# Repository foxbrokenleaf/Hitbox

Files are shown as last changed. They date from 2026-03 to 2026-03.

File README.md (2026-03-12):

# HitBox

## 成品
微信图片_20260312213438_205_17

## 成本统计（因人而异）
### 原价（参考价）
+ 覆铜板15x20cm - 4.91￥
+ 猎隼mini矮轴*6 - 21￥
+ 猎隼mini矮轴*8 - 28￥
+ STM32F103C8T6 - 14.97￥
+ USB-B接口*5 - 3.35￥
+ 1x20p排母*10 - 2.62￥
### 使用优惠卷（我）
+ 覆铜板15x20cm - 2.22￥
+ 猎隼mini矮轴*6 - 15.8￥
+ 猎隼mini矮轴*8 - 16.8￥
+ STM32F103C8T6 - 2.47￥
+ USB-B接口*5 - 0.95￥
+ 1x20p排母*10 - 2.62￥
## PCB成品预览
正面预览图

## 制板
### 热转印法
#### 工具材料
+ 热转印机/熨斗
+ 热转印纸
+ 激光打印机
+ 覆铜板
+ 砂纸/钢丝球
+ 蚀刻剂
#### 热转印
使用激光打印机将镜像的PCB打印到转印纸（反光面）上，然后使用热转印机或者熨斗按压转印，然后缓慢揭开热转印纸

#### 蚀刻
配置蚀刻液，将转印好的PCB放入蚀刻液中，确保溶液没过PCB板


### 感光法（未购买相关材料）

## 3D打印键帽
### 正面

### 背面

## 后续更新
+ 将最小系统板改为芯片
+ 将USB-B改为Type-C

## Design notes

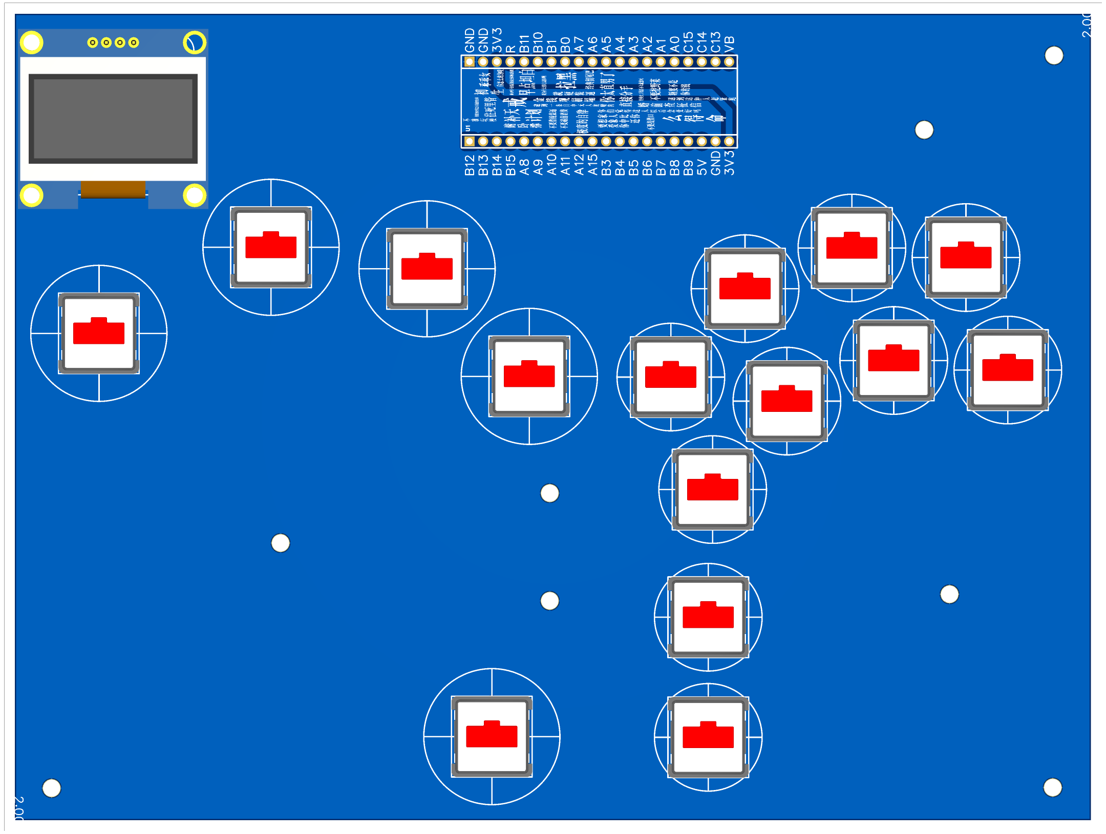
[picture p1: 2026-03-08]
EleCircurt/正面预览图.png

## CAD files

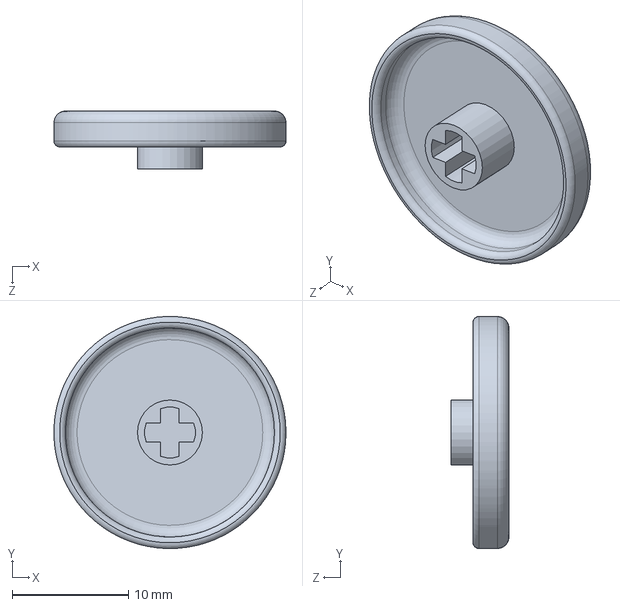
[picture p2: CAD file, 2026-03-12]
3DMoudle/HitboxKey-20mm.SLDPRT
20.0 x 20.0 x 5.00 mm

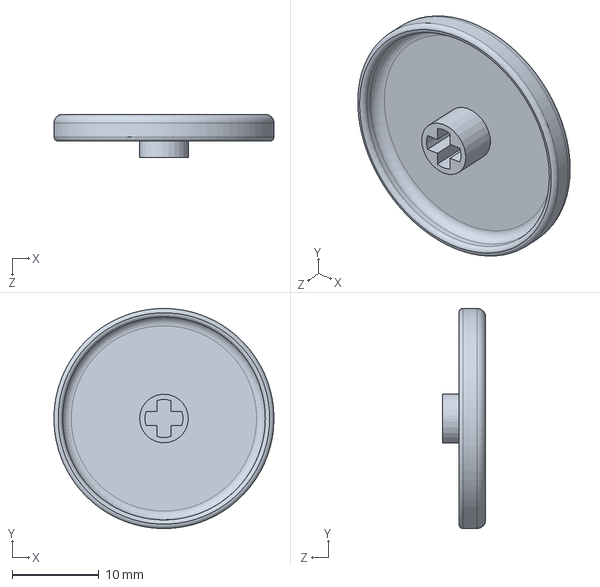
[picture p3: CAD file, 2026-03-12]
3DMoudle/HitboxKey-25_3mm.SLDPRT
25.3 x 25.3 x 5.00 mm

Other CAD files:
3DMoudle/HitboxKey-20mm.3MF
3DMoudle/HitboxKey-25_3mm.3MF

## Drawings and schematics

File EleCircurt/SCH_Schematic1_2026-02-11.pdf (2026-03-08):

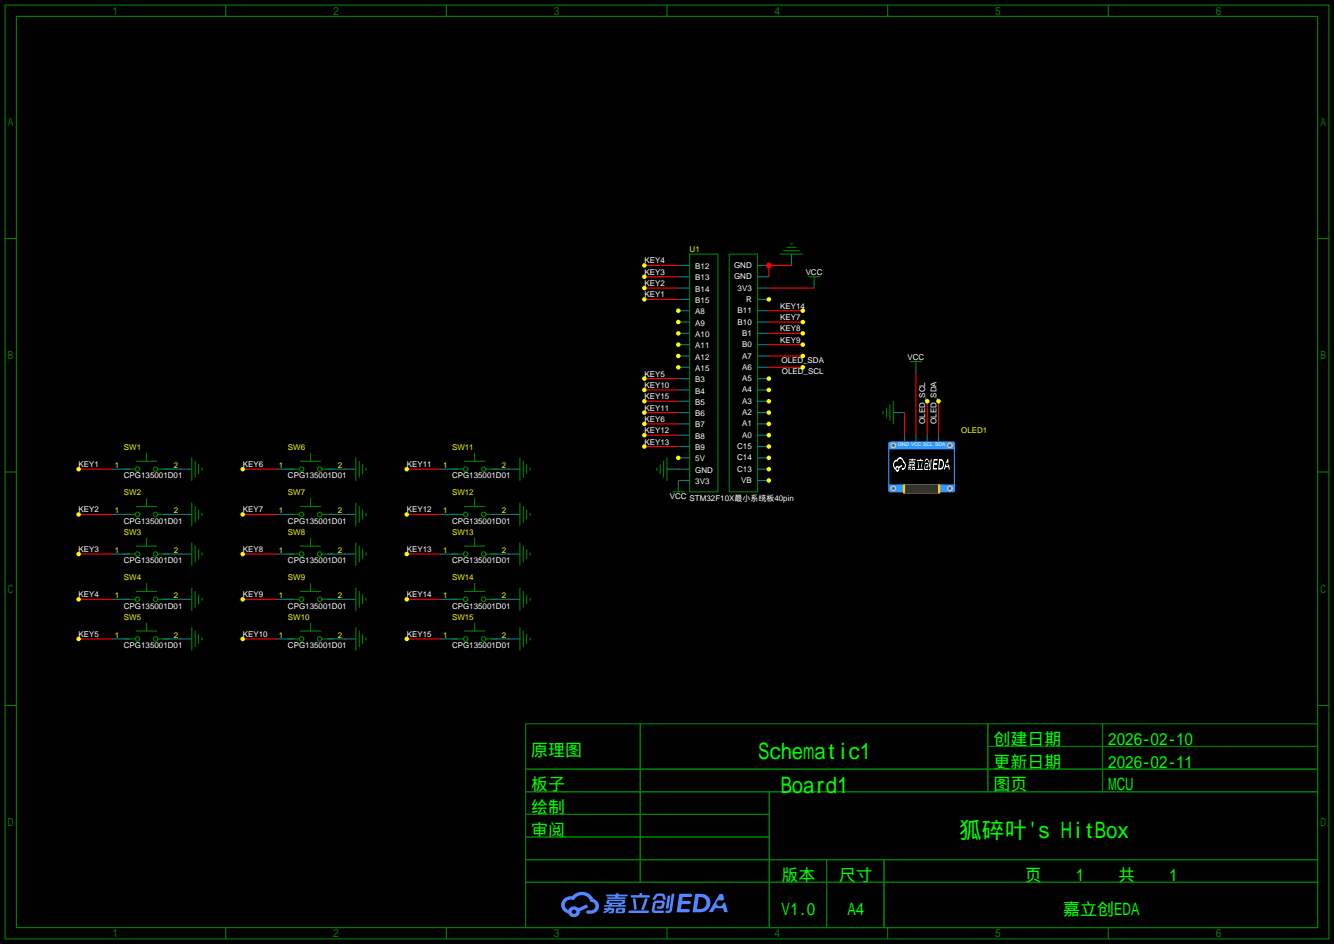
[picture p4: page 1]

GND VCC SCL SDA

原理图 | Schematic1 | 创建日期 | 2026-02-10

更新日期 | 2026-02-11

板子 | Board1 | 图页 | MCU
绘制 | | 狐碎叶's HitBox
审阅

V1.0 | A4 | 嘉立创EDA

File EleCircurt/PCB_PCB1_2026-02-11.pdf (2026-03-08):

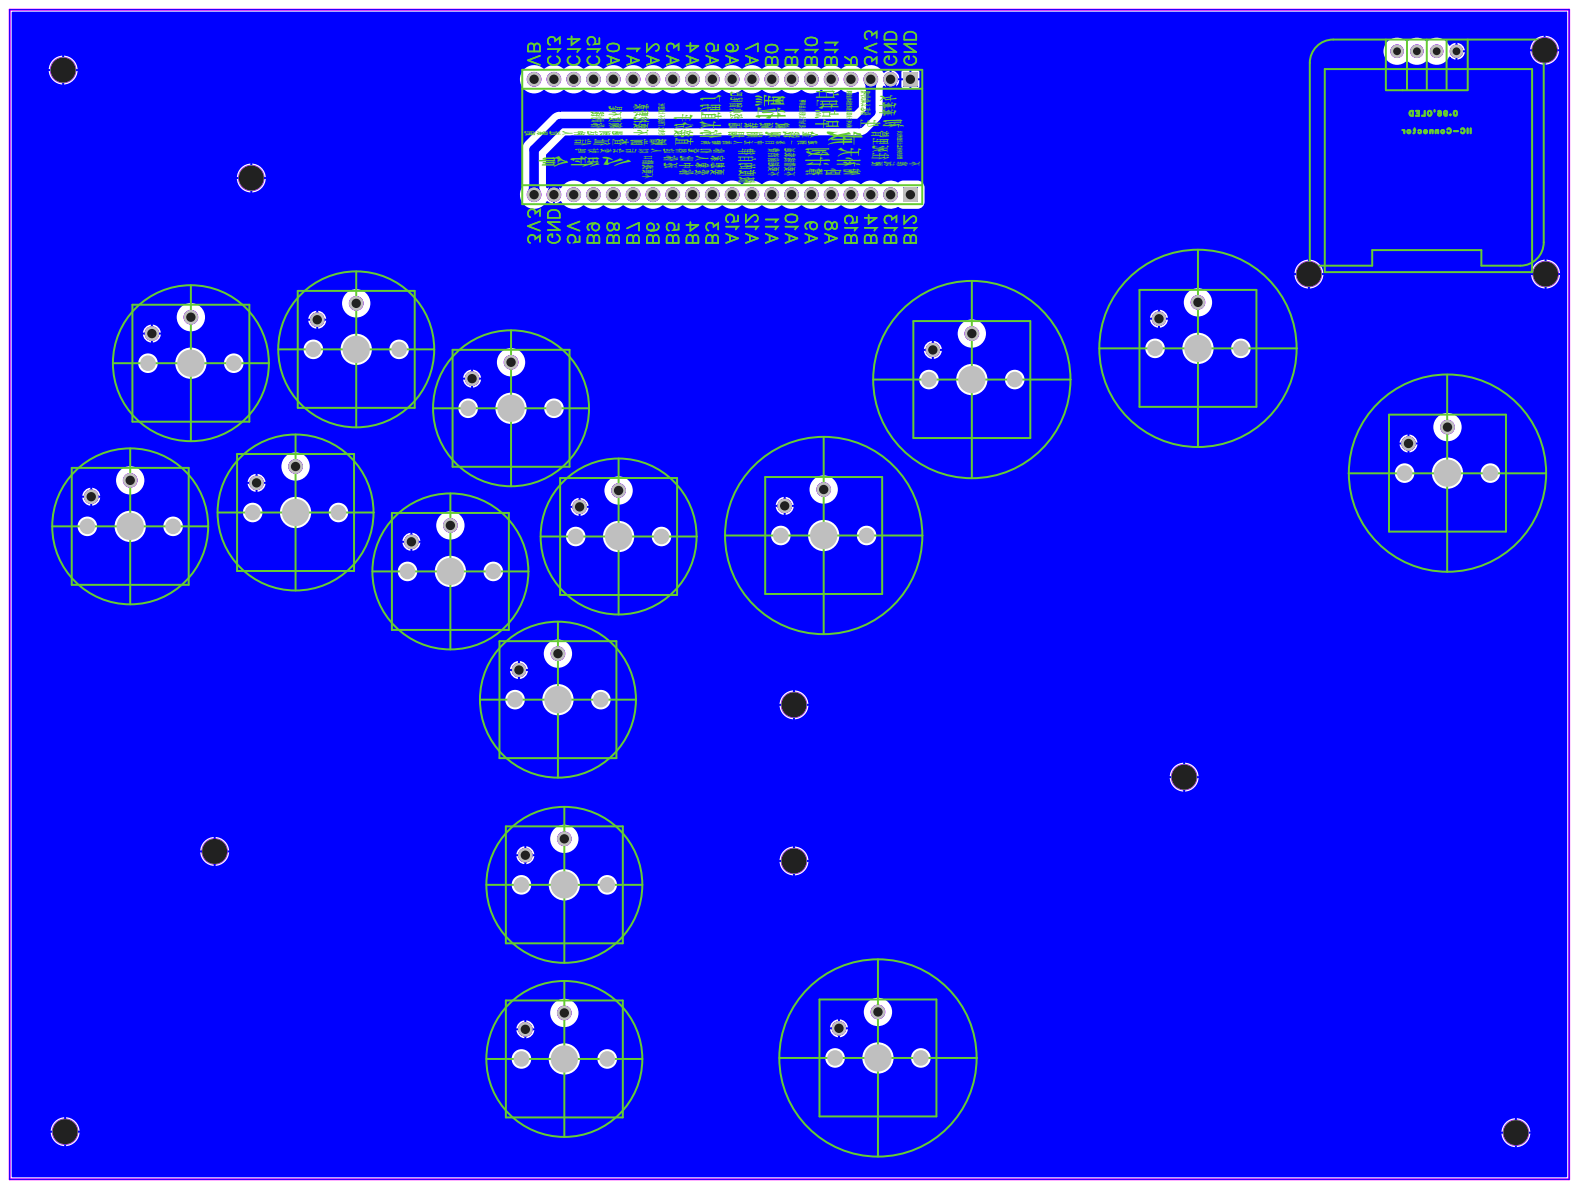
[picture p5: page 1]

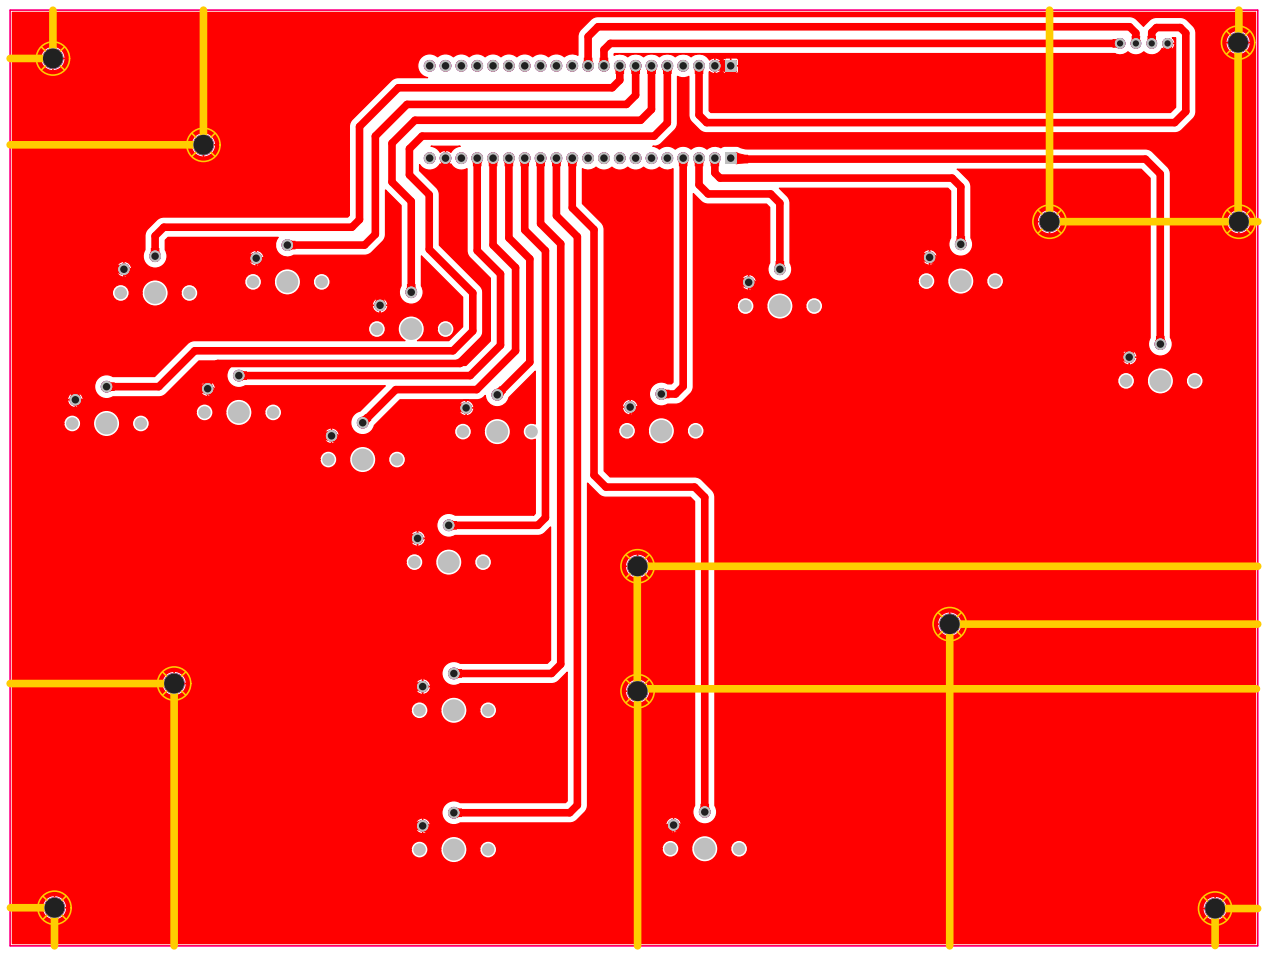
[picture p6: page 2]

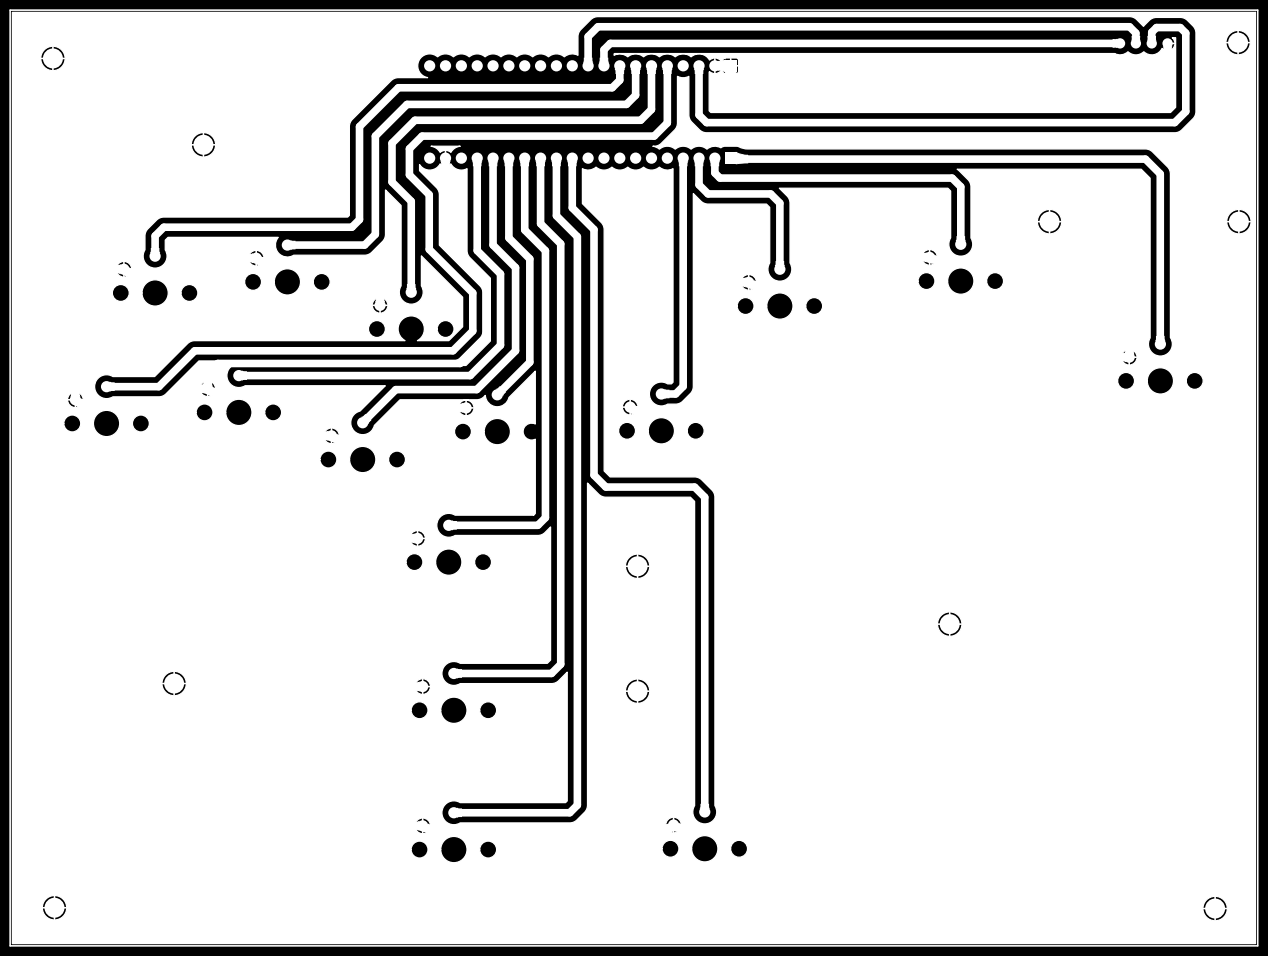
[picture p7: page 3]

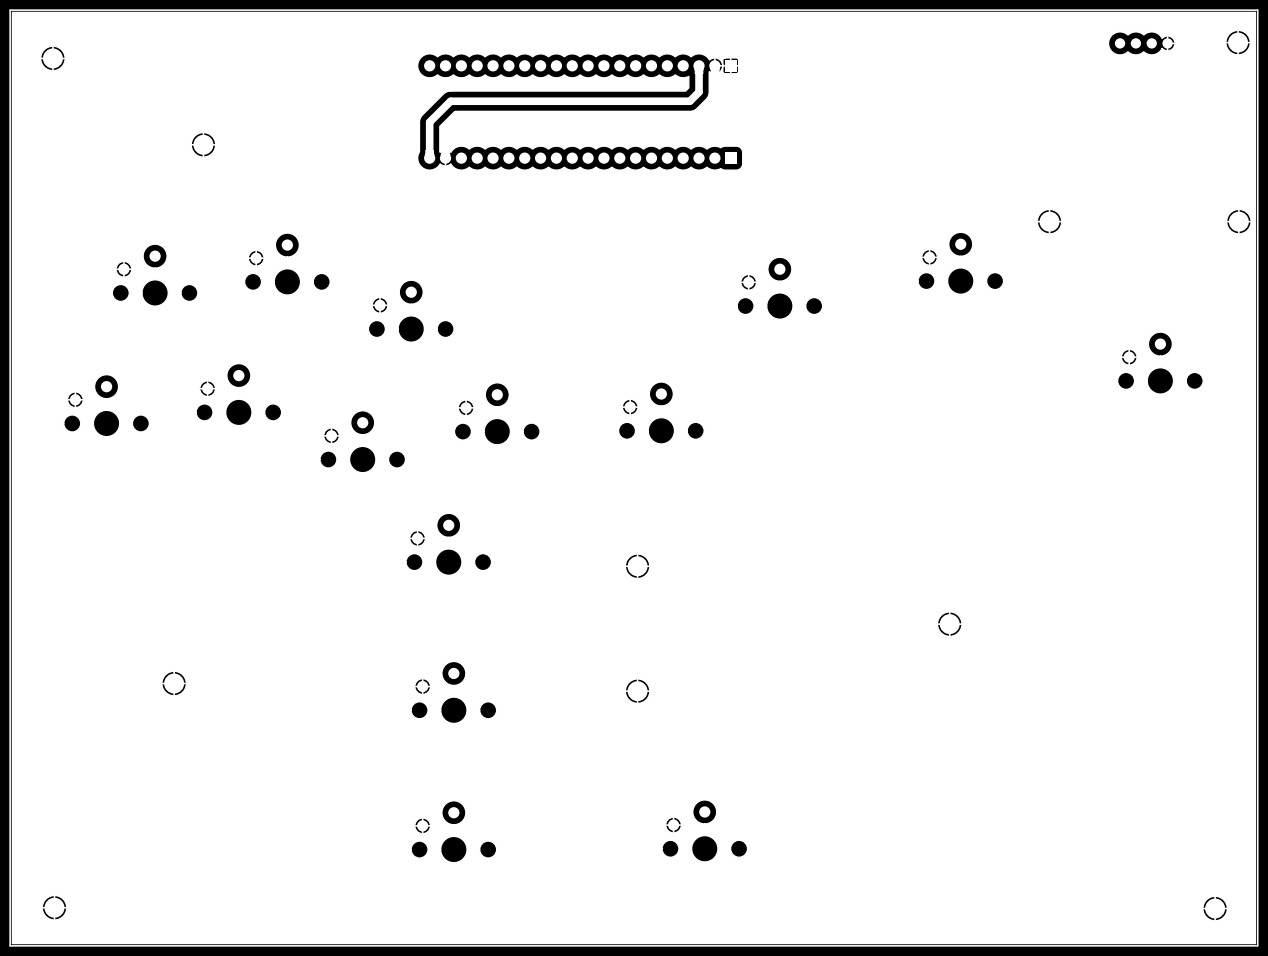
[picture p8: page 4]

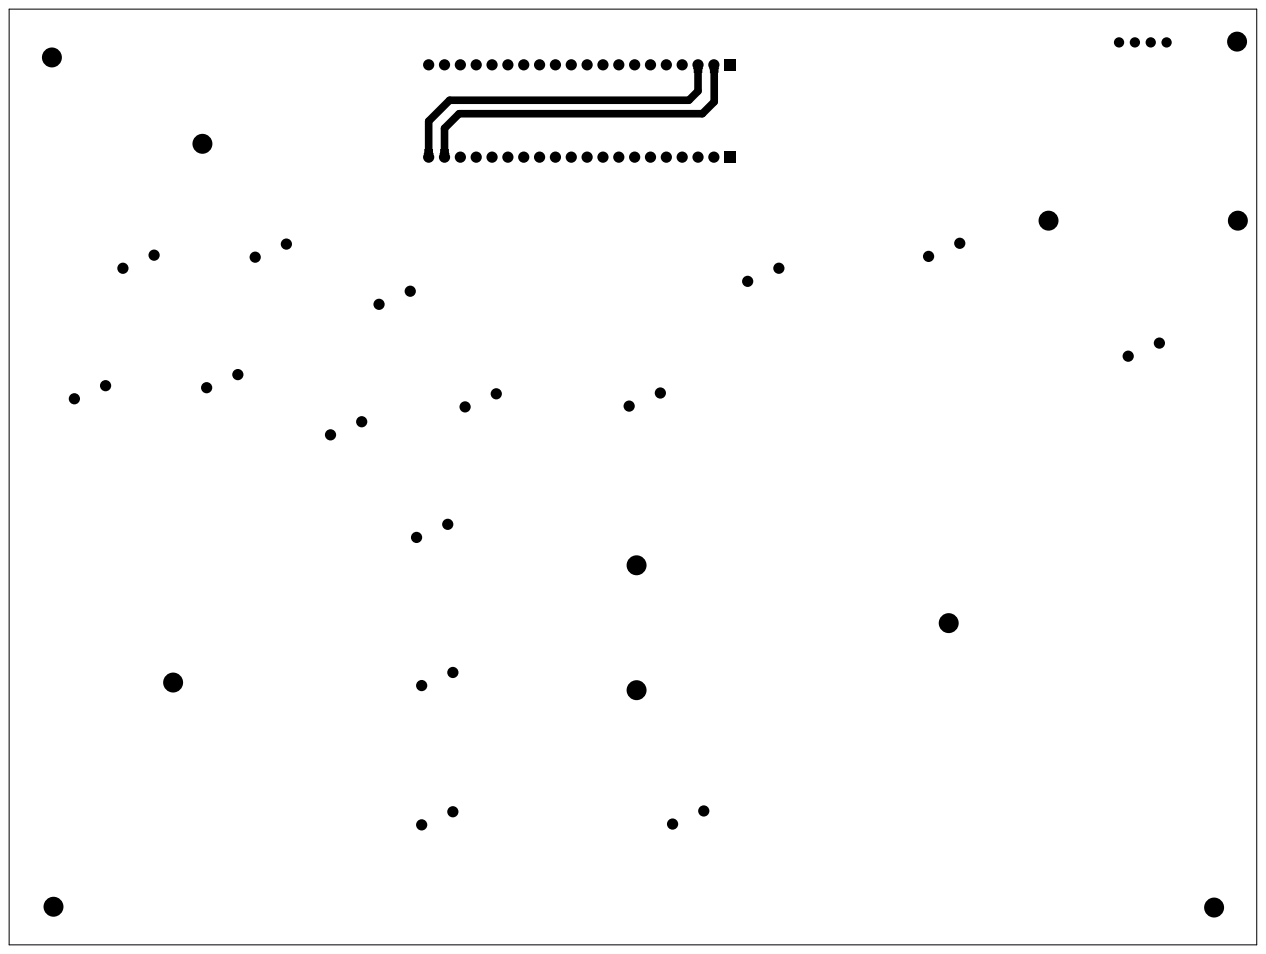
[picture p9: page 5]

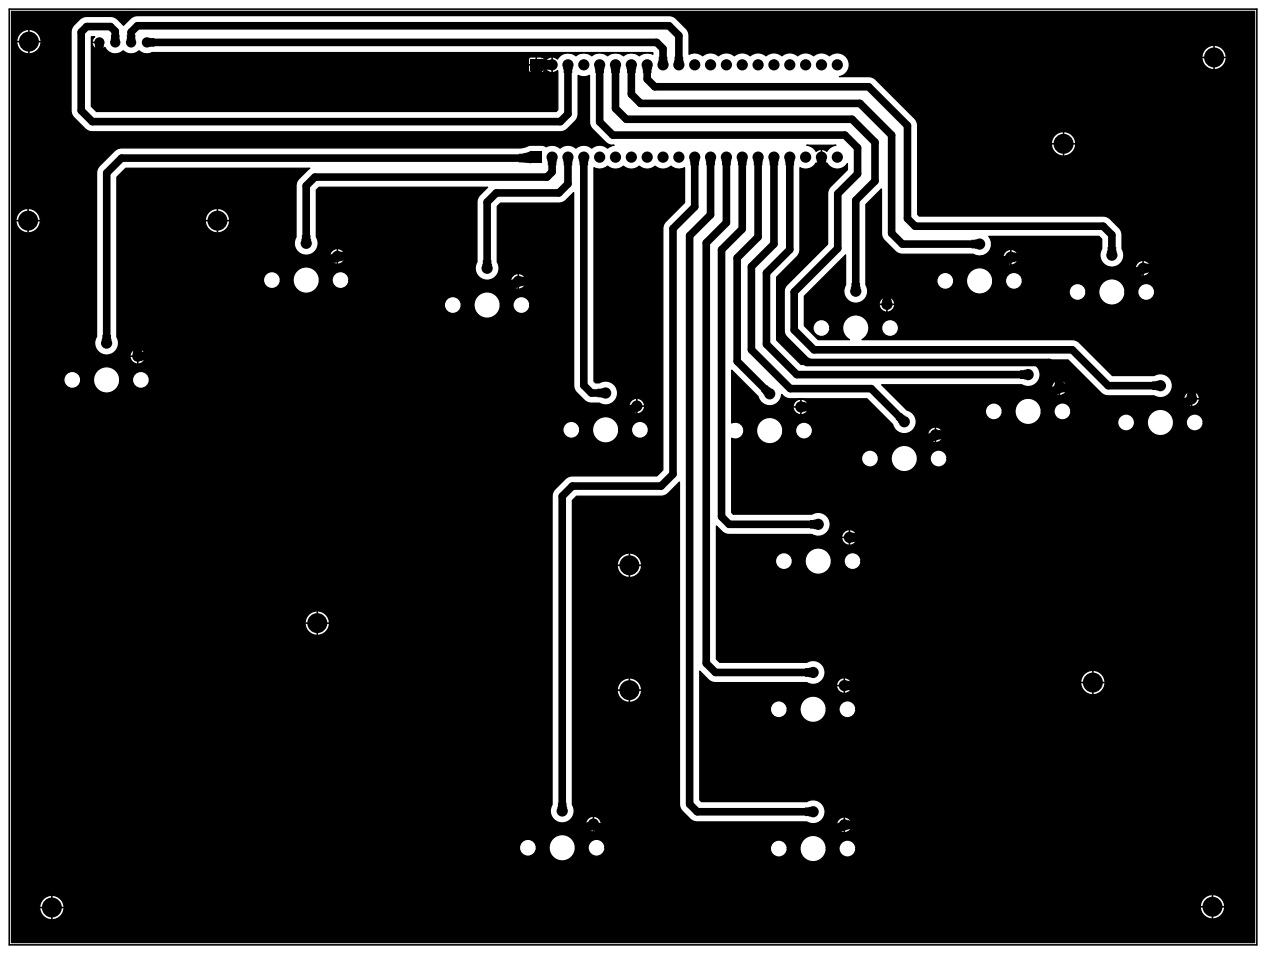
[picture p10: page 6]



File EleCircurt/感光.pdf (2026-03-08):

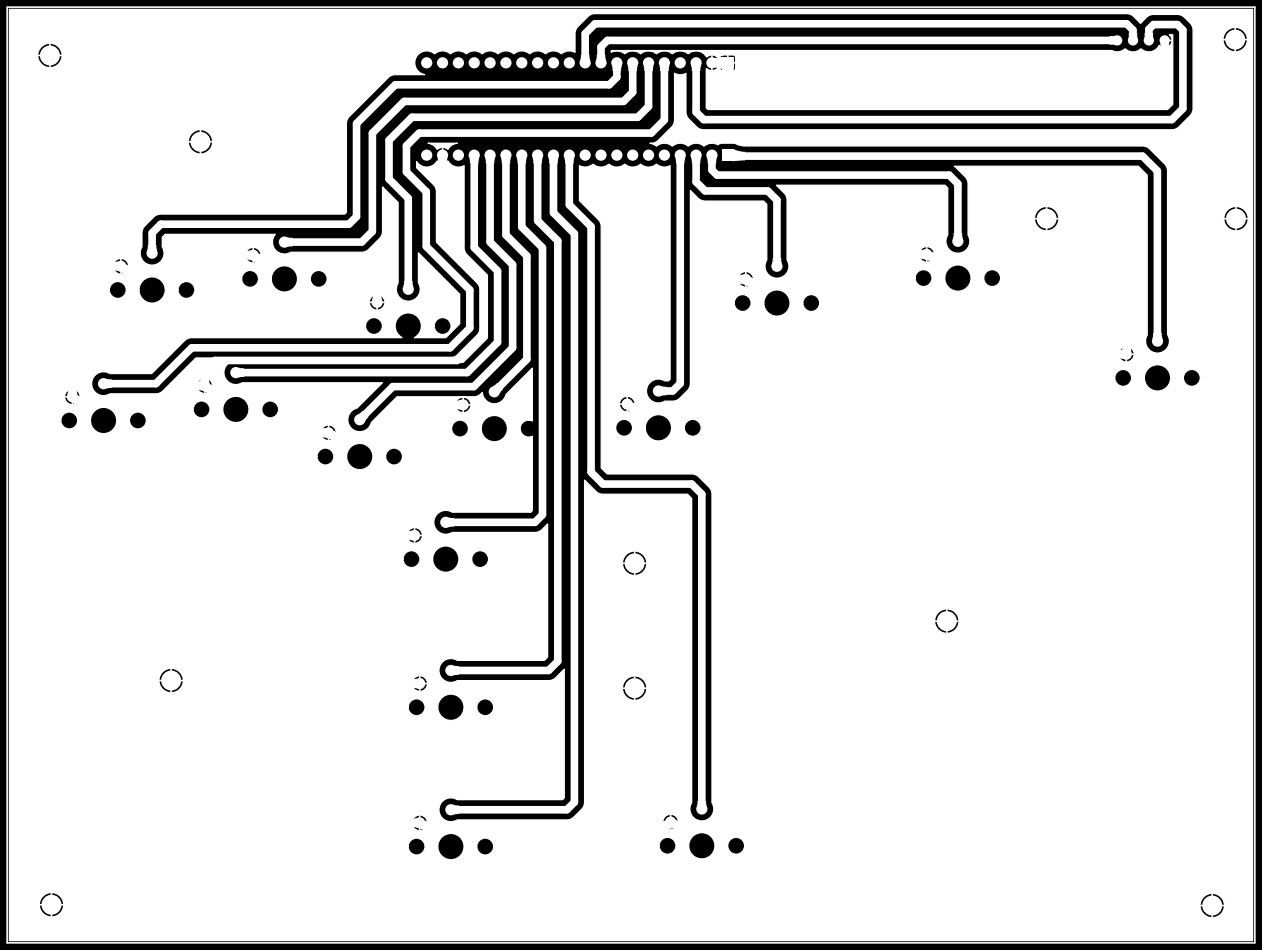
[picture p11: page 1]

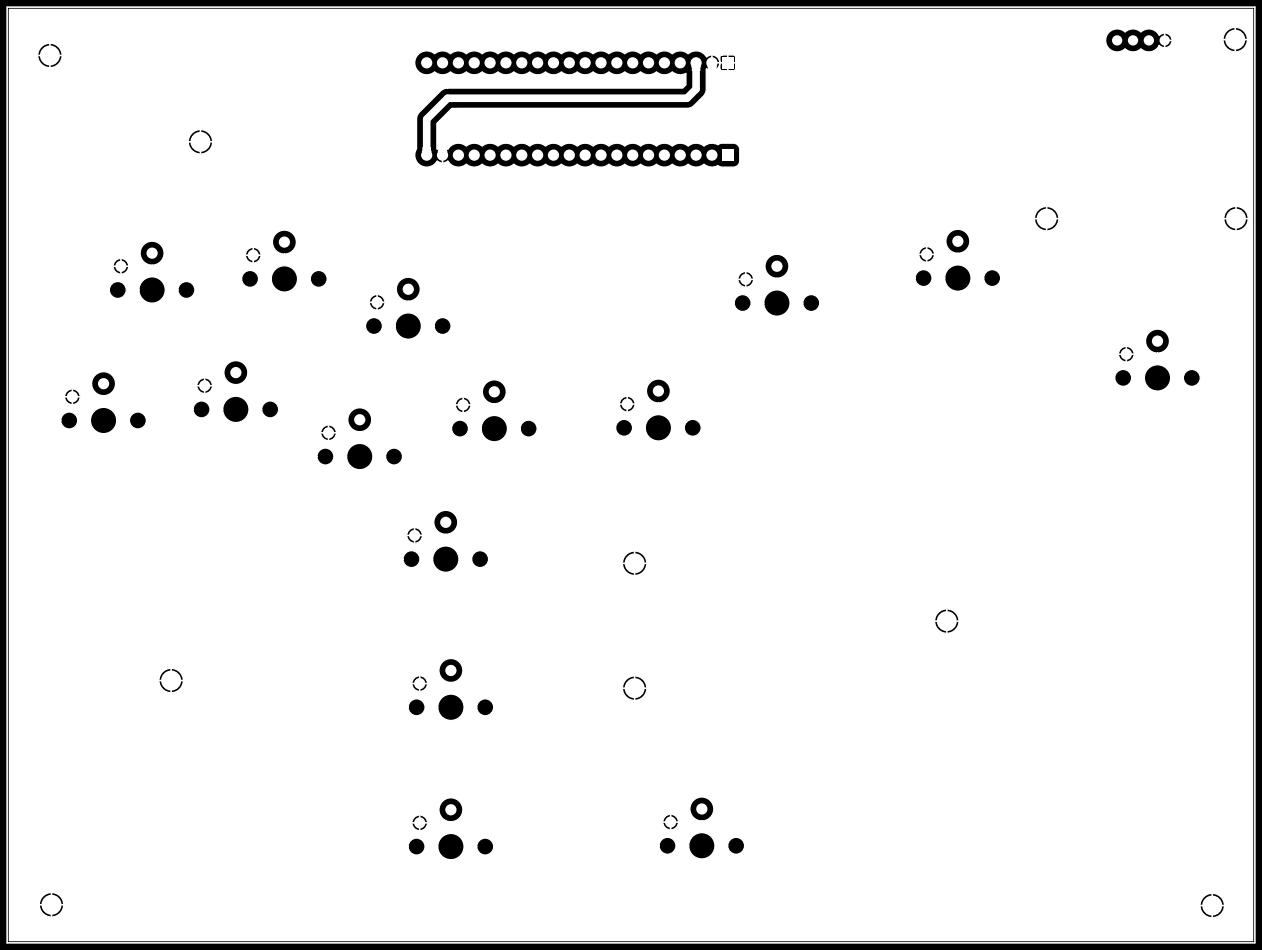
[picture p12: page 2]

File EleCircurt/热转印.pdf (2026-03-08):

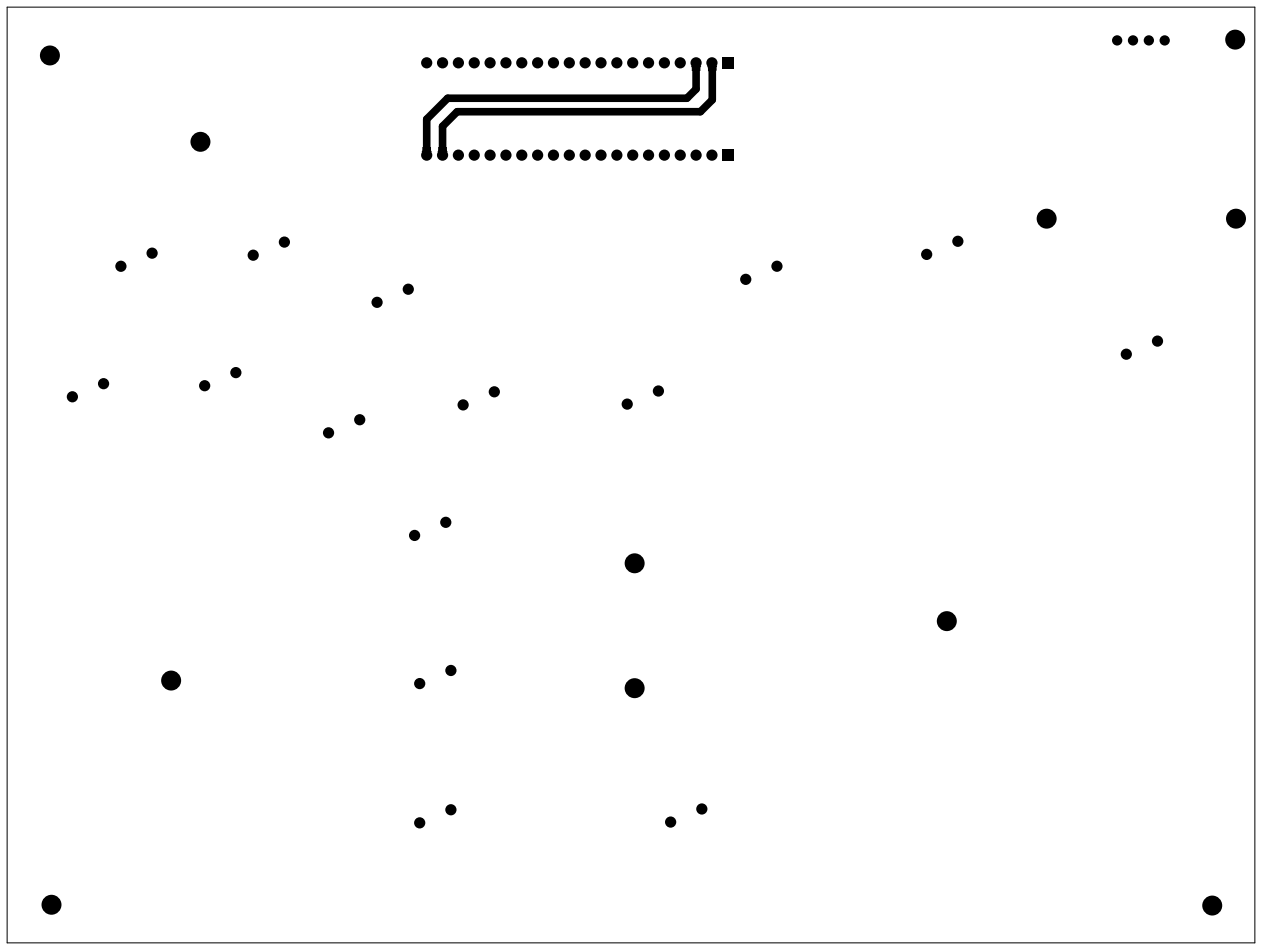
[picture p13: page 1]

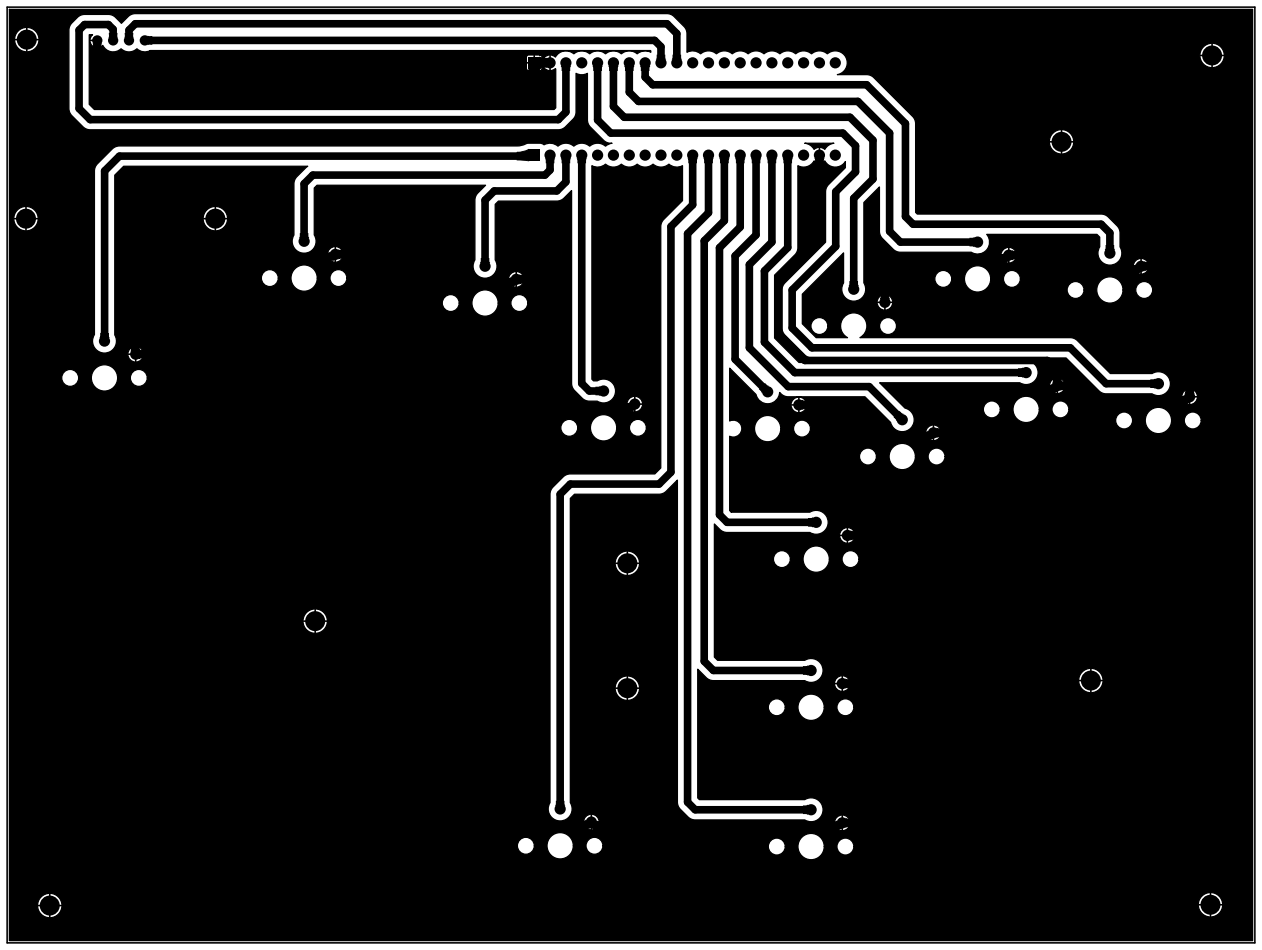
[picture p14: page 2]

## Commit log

2026-03-08 硬件V0.0
2026-03-08 更新README.md
2026-03-08 完成了键帽的3d模型设计
    [HitboxKey-20mm.3MF, HitboxKey-20mm.SLDPRT, HitboxKey-25_3mm.3MF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]
2026-03-12 优化键帽的结构
    [HitboxKey-20mm.3MF, HitboxKey-20mm.SLDPRT, HitboxKey-25_3mm.3MF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]
